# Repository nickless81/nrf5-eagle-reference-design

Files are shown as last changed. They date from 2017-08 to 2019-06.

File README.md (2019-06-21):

# Nordic semiconductor eagle reference design

## Reference designs


The reference designs supplied for eagle are made by following the [general pcb design guidelines][designguidenrf52] and referencing the [altium reference layout][altiumreference].
The eagle reference design is not the official reference designs, only the Altium reference designs has been tested and verified. They are available for download in Nordic's product pages.
The reference designs include eagle files as well as pdf printouts. For BOM see the altium reference designs.

* nRF51x22_qfaa
* nRF51x22_qfaa_dcdc
* nRF52832_qfaa
* nRF52832_qfaa_dcdc
* nRF52832_qfaa_nfc

## Libraries
**The libraries are not verified, only the Altium reference designs has been tested and verified.**

### Nordic_nRF
This library contains the nRF51 and nRF52 in qfn and bga packages, as well as; capacitors, inductors, and a 32MHz and 32kHz xtal. All that is needed for the core reference design. (link?)

### Nordic_misc
This library contains the rest of the components used in the sample eagle design(s) in this repository, as well as some simple antenna suggestions.

## Antenna
In the Nordic_misc library there is supplied some suggestions for antennas, please note that antenna characteristics depends greatly on the board layout. These antennas are made according to the [whitepaper][monopole] on quarter wave monopole 2.45 GHz antennas. Remember to [tune][antuning] the antenna

## NFC
An NFC listener antenna suggestion is supplied in the Nordic_misc library, this is the antenna used in the [nRF52-DK] development kit. Remember to [tune][nfctune] the antenna.

[github]: <https://github.com/NordicPlayground/nrf5-eagle-reference-design>
[designguidenrf51]: <https://devzone.nordicsemi.com/blogs/655/general-pcb-design-guidelines-for-nrf51/>
[designguidenrf52]: <https://devzone.nordicsemi.com/blogs/870/general-pcb-design-guidelines-for-nrf52/>
[referencecircuitry]: <https://infocenter.nordicsemi.com/index.jsp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>
[altiumreference]: <http://infocenter.nordicsemi.com/index.jsp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>
[nfctune]: <https://devzone.nordicsemi.com/blogs/957/nfc-tag-antenna-tuning/>
[nRF52-DK]: <http://www.nordicsemi.com/eng/Products/Bluetooth-low-energy2/nRF52-DK>
[dcdc_reference]: <nRF52832_qfaa_dcdc_reference.png>
[monopole]: <http://infocenter.nordicsemi.com/topic/com.nordic.infocenter.whitepapers/dita/whitepapers/pdflinks/nwp_008.html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>
[antuning]: <https://infocenter.nordicsemi.com/topic/com.nordic.infocenter.whitepapers/dita/whitepapers/pdflinks/nwp_017.html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>

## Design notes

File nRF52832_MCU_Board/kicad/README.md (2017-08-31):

## Reference designs
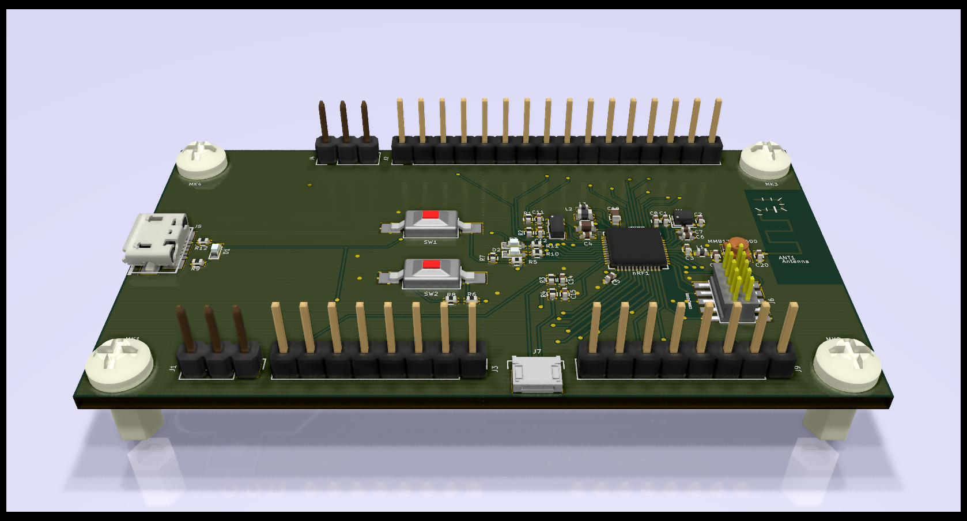
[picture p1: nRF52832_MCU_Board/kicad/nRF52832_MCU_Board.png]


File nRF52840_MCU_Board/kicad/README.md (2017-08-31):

## Reference designs
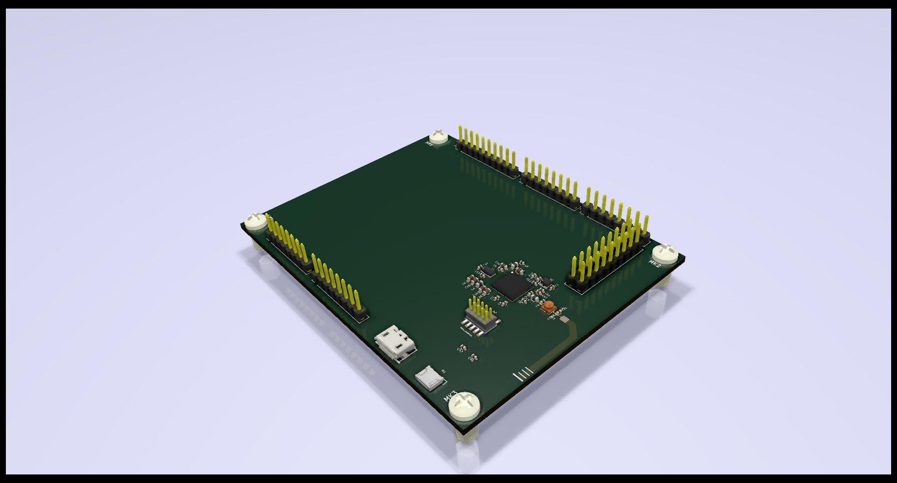
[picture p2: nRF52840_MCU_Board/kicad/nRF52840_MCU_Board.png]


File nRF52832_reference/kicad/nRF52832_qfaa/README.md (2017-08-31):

## Reference designs
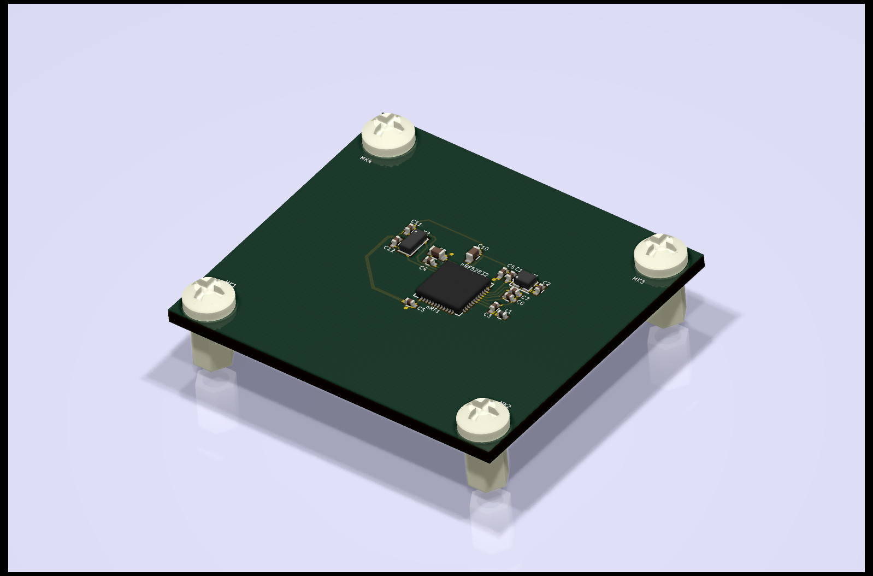
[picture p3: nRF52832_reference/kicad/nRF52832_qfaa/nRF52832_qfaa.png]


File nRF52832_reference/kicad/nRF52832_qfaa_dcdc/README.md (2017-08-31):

## Reference designs
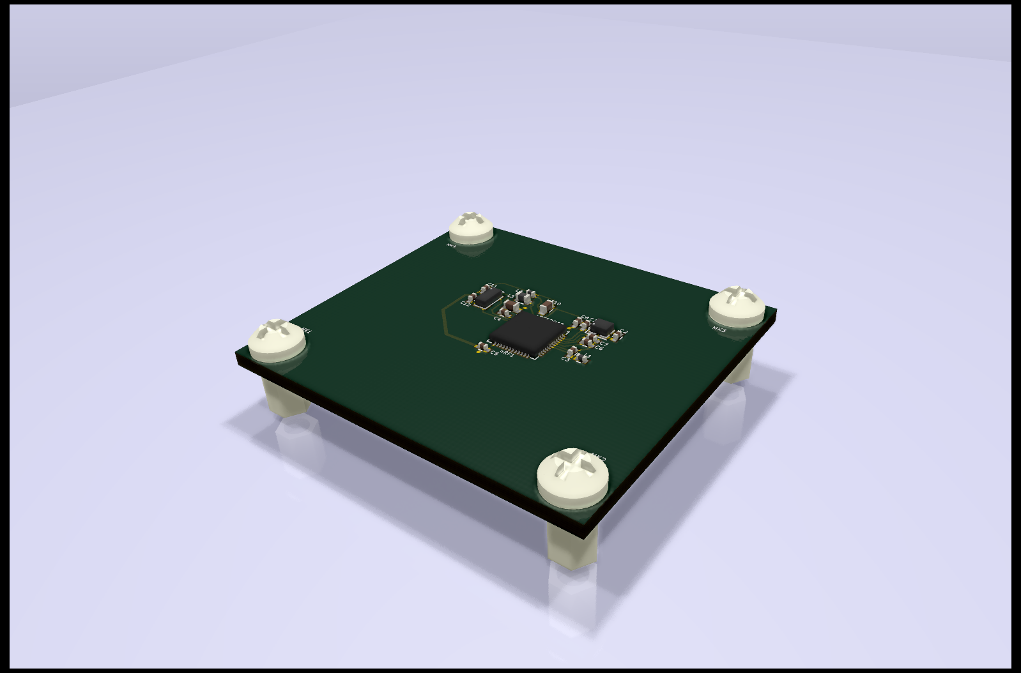
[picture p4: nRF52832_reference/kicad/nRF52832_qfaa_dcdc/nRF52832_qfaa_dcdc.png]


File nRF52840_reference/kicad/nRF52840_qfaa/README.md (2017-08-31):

## Reference designs
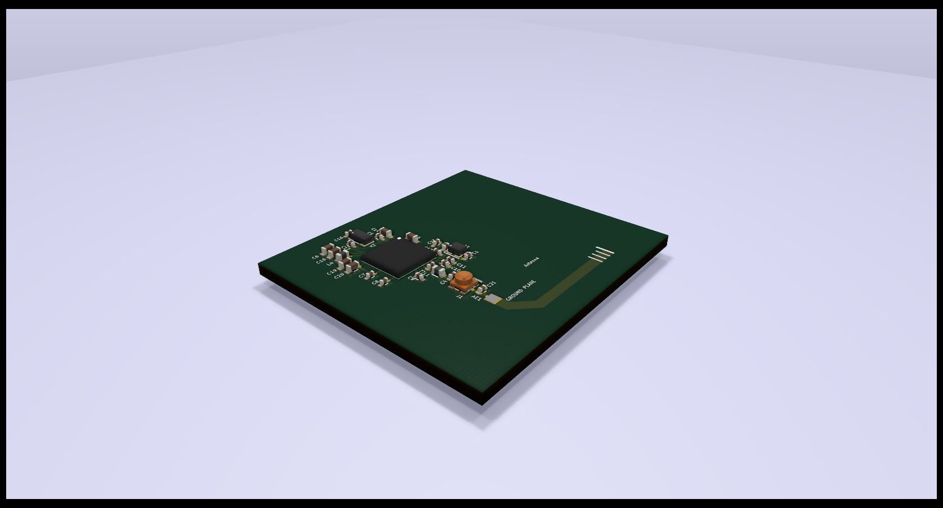
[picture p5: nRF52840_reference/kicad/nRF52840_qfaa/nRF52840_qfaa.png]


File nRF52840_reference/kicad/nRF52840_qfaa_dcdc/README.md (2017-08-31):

## Reference designs
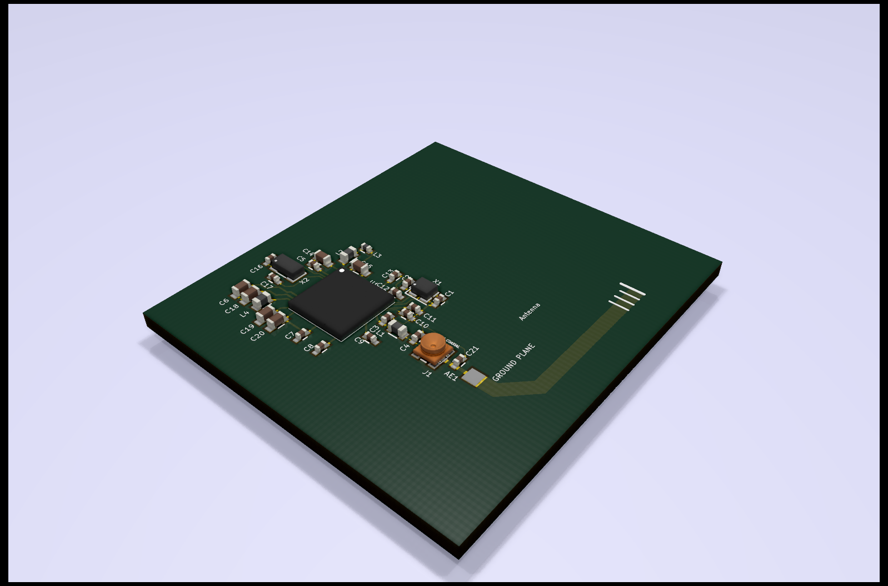
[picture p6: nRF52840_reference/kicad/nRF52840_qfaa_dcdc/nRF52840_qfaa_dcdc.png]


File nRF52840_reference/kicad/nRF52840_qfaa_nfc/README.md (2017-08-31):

## Reference designs
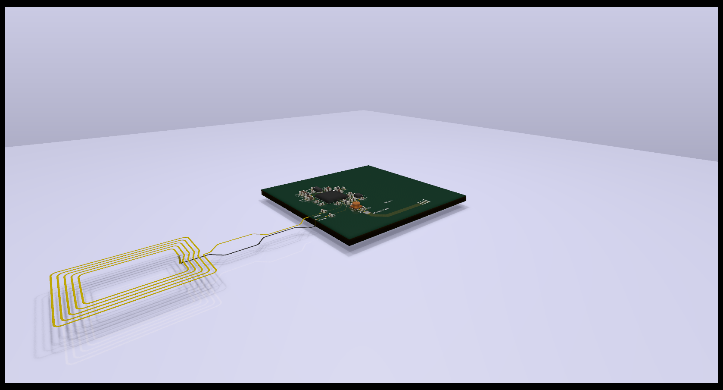
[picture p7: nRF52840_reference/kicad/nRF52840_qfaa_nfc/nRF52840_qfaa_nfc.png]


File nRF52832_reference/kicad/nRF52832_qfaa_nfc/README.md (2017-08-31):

## Reference designs
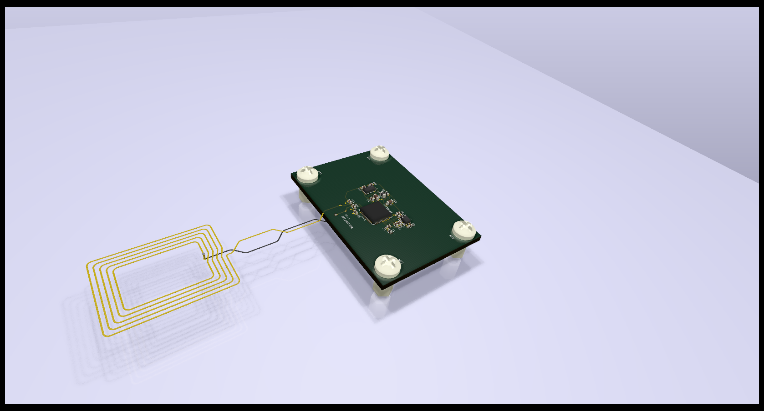
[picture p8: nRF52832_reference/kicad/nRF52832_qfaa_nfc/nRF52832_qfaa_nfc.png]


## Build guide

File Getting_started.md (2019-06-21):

# Getting started with nRF5 and CadSoft EAGLE (R)

Nordic Semiconductor already provides [reference designs][altiumreference] for Altium Designer (R), but if you prefer EAGLE here is a quick guide on how to use the EAGLE reference design.

This quick guide assumes you are familiar with doing PCB designs in EAGLE, otherwise both [Adafruit] and [SparkFun] have guides on how to get started.

1. First clone or download the reference designs and libraries from [Github]
2. Select the reference-design that fits your application (if you are uncertain use *nRF52832_qfaa_dcdc*)
3. Add your own parts in the circuit diagram
4. Create the layout and routing
	* Do not modify the geometry of the rf part

Please refer to the general pcb design guidelines for [nRF51][designguidenrf51] or [nRF52][designguidenrf52].

### 1. First clone or download the reference designs and libraries from [Github]

If you are familiar with [git] this is self explanatory, if not press the (green) "Clone or download" button and then "Download ZIP".

### 2. Select the reference-design that fits your application

All reference designs supplied here are for the QFN package.
If you want to use the internal ldo (not recommended) select nRF5\*_qfaa, if you want an example of nfc antenna usage select nRF5\*_qfaa_nfc.
You probably want the nRF51x2_qfaa_dcdc or nRF52832_qfaa_dcdc, for nRF51 or nRF52 respectively.

### 3. Add your own parts in the circuit diagram

Here is the part where you do your design, use your own libraries, use libraries supplied with eagle, use parts from the Nordic_misc library, make your own parts, etc.

### 4. Do the layout and routing

This is also a part of your regular workflow. Lay out your design next to or around the reference layout.

#### Do not modify the geometry of the rf part

Now, the important part: Do not add components close to the rf layout. This means around where you attach the antenna (the signal named RF).
The cutout in the ground plane is there for a reason. Add cutouts to any internal layers of the pcb as well. There should be a ground plane on the bottom layer.
Add a generous amount of ground stiching vias (remember vias are free).

### 5. Done

There. You are done with your nRF5 design in eagle, dont forget to run design reviews before ordering pcbs. And dont forget to tune the antenna when you have your prototype in hand.

# Some info on the git repository

## Reference designs


The reference designs supplied for eagle are made by following the [general pcb design guidelines][designguidenrf52] and referencing the [altium reference layout][altiumreference].
The reference designs include eagle files as well as pdf printouts. For BOM see the altium reference designs.

* nRF51x22_qfaa
* nRF51x22_qfaa_dcdc
* nRF52832_qfaa
* nRF52832_qfaa_dcdc
* nRF52832_qfaa_nfc

## Libraries

### Nordic_nRF
This library contains the nRF51 and nRF52 in QFN and bga packages, as well as; capacitors, inductors, and a 32MHz and 32kHz xtal. All that is needed for the core reference design.

### Nordic_misc
This library contains the rest of the components used in the sample eagle design(s) in the github repository, as well as some simple antenna suggestions.

## Antenna
In the Nordic_misc library there is supplied some suggestions for antennas, please note that antenna characteristics depends greatly on the board layout. These antennas are made according to the [whitepaper][monopole] on quarter wave monopole 2.45 GHz antennas. Remember to [tune][antuning] the antenna.

## NFC
An NFC listener antenna suggestion is supplied in the Nordic_misc library, this is the antenna used in the [nRF52-DK] development kit. Remember to [tune][nfctune] the antenna.

[sparkfun]: <https://www.sparkfun.com/>
[adafruit]: <https://www.adafruit.com/>
[github]: <https://github.com/NordicPlayground/nrf5-eagle-reference-design>
[designguidenrf51]: <https://devzone.nordicsemi.com/blogs/655/general-pcb-design-guidelines-for-nrf51/>
[designguidenrf52]: <https://devzone.nordicsemi.com/blogs/870/general-pcb-design-guidelines-for-nrf52/>
[referencecircuitry]: <https://infocenter.nordicsemi.com/index.jsp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>
[altiumreference]: <http://infocenter.nordicsemi.com/index.jsp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>
[nfctune]: <https://devzone.nordicsemi.com/blogs/957/nfc-tag-antenna-tuning/>
[nRF52-DK]: <http://www.nordicsemi.com/eng/Products/Bluetooth-low-energy2/nRF52-DK>
[dcdc_reference]: <nRF52832_qfaa_dcdc_reference.png>
[monopole]: <http://infocenter.nordicsemi.com/topic/com.nordic.infocenter.whitepapers/dita/whitepapers/pdflinks/nwp_008.html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>
[antuning]: <https://infocenter.nordicsemi.com/topic/com.nordic.infocenter.whitepapers/dita/whitepapers/pdflinks/nwp_017.html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>
[git]: <https://git-scm.com/>

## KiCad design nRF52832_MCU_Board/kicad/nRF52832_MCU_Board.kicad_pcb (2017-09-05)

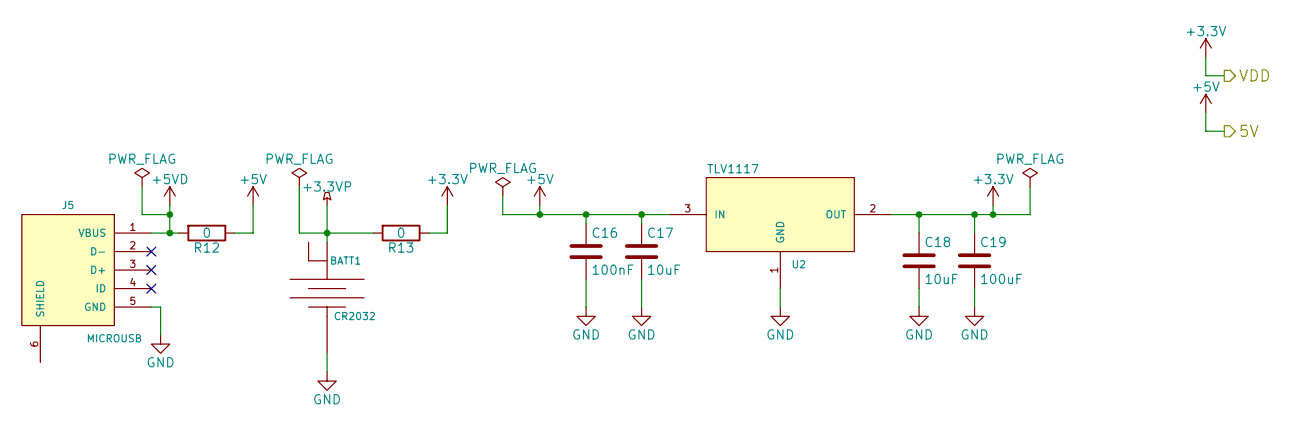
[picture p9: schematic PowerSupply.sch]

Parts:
BATT1: CR2032; keystone_3003
C16: 100nF; C_0402
C17, C18: 10uF; C_0603
C19: 100uF; C_0805
J5: MICROUSB; conn_usb_B_micro_smd
R12, R13: 0; R_0402
U2: TLV1117; SOT-223-3Lead_TabPin2

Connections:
+3.3VP: BATT1.2 (+), R13.2
+3V3: C18.1, C19.1, R13.1, U2.2 (OUT); also elsewhere on the board
+5V: C16.1, C17.1, R12.1, U2.3 (IN); also elsewhere on the board
+5VD: J5.1 (VBUS), R12.2
GND: BATT1.1 (-), C16.2, C17.2, C18.2, C19.2, J5.5 (GND), U2.1 (GND); also elsewhere on the board

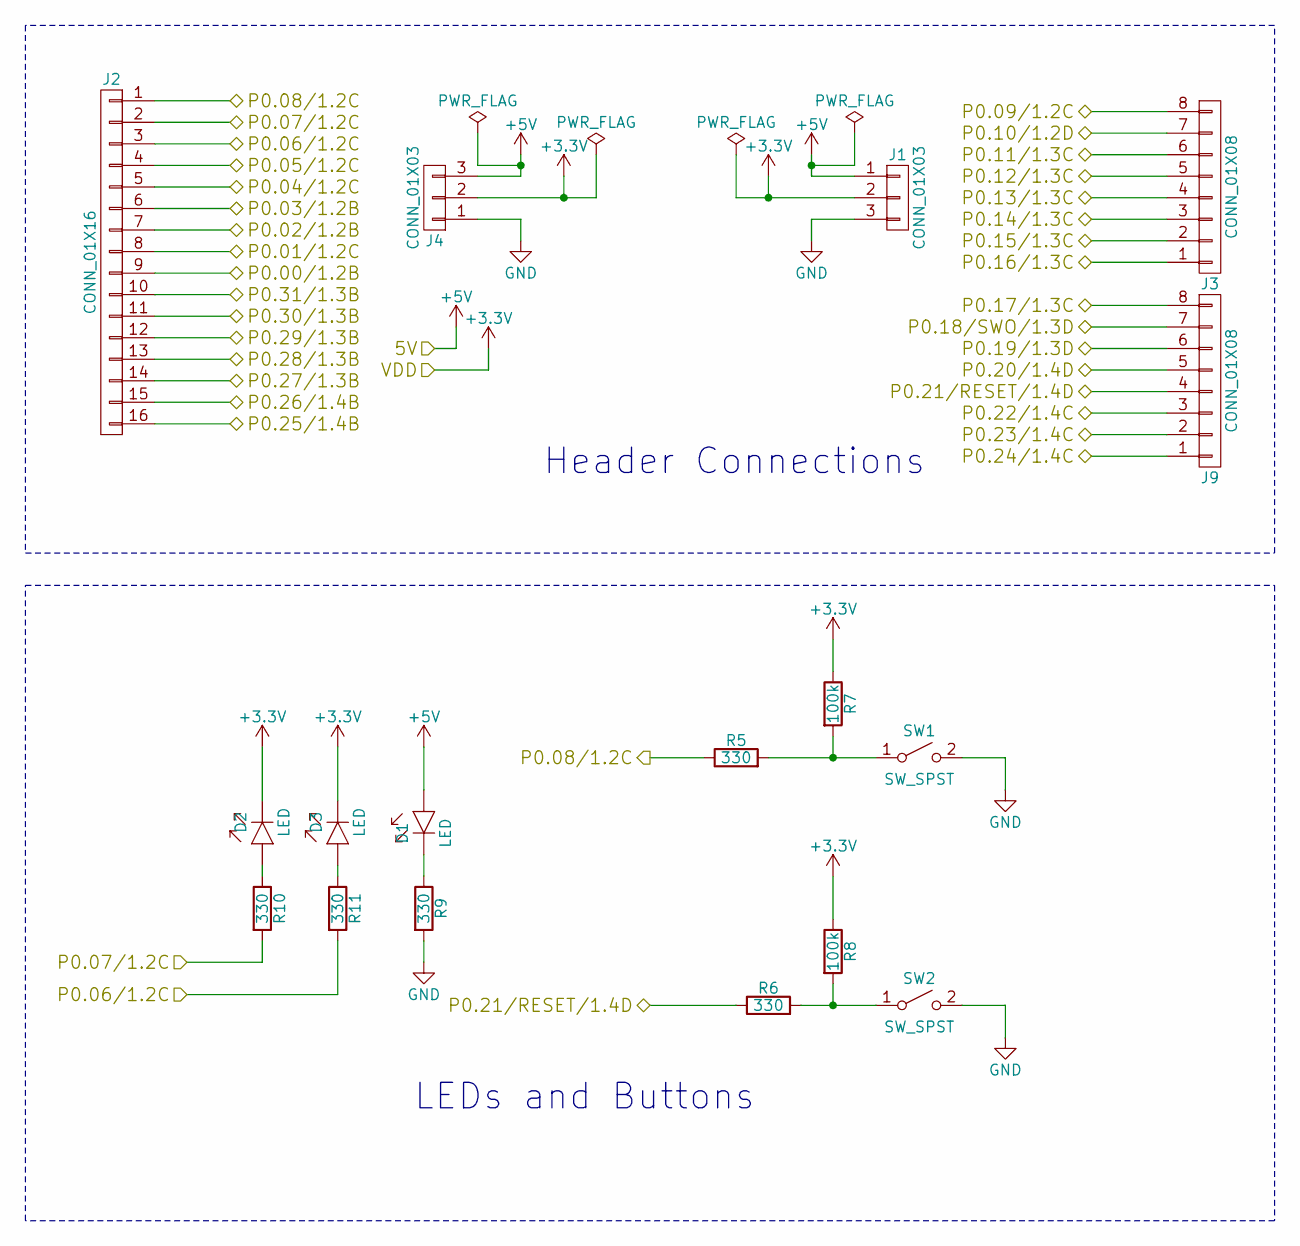
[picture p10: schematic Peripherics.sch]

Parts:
D1, D2, D3: LED; LED_0603
J1, J4: CONN_01X03; Pin_Header_Straight_1x03_Pitch2.54mm
J2: CONN_01X16; Pin_Header_Straight_1x16_Pitch2.54mm
J3, J9: CONN_01X08; Pin_Header_Straight_1x08_Pitch2.54mm
R5, R6, R9, R10, R11: 330; R_0402
R7, R8: 100k; R_0402
SW1, SW2: SW_SPST; SW_SPST_FSMSM

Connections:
+3V3: D2.1 (C), D3.1 (C), J1.2, J4.2, R7.1, R8.1; also elsewhere on the board
+5V: D1.2 (A), J1.1, J4.3; also elsewhere on the board
/P0.00: J2.9; also elsewhere on the board
/P0.01: J2.8; also elsewhere on the board
/P0.02: J2.7; also elsewhere on the board
/P0.03: J2.6; also elsewhere on the board
/P0.04: J2.5; also elsewhere on the board
/P0.05: J2.4; also elsewhere on the board
/P0.06: J2.3, R11.2; also elsewhere on the board
/P0.07: J2.2, R10.2; also elsewhere on the board
/P0.08: J2.1, R5.1; also elsewhere on the board
/P0.09: J3.8; also elsewhere on the board
/P0.10: J3.7; also elsewhere on the board
/P0.11: J3.6; also elsewhere on the board
/P0.12: J3.5; also elsewhere on the board
/P0.13: J3.4; also elsewhere on the board
/P0.14: J3.3; also elsewhere on the board
/P0.15: J3.2; also elsewhere on the board
/P0.16: J3.1; also elsewhere on the board
/P0.17: J9.8; also elsewhere on the board
/P0.18: J9.7; also elsewhere on the board
/P0.19: J9.6; also elsewhere on the board
/P0.20: J9.5; also elsewhere on the board
/P0.21: J9.4, R6.1; also elsewhere on the board
/P0.22: J9.3; also elsewhere on the board
/P0.23: J9.2; also elsewhere on the board
/P0.24: J9.1; also elsewhere on the board
/P0.25: J2.16; also elsewhere on the board
/P0.26: J2.15; also elsewhere on the board
/P0.27: J2.14; also elsewhere on the board
/P0.28: J2.13; also elsewhere on the board
/P0.29: J2.12; also elsewhere on the board
/P0.30: J2.11; also elsewhere on the board
/P0.31: J2.10; also elsewhere on the board
GND: J1.3, J4.1, R9.2, SW1.2 (B), SW2.2 (B); also elsewhere on the board
unnamed: D1.1 (C), R9.1
unnamed: D2.2 (A), R10.1
unnamed: D3.2 (A), R11.1
unnamed: R5.2, R7.2, SW1.1 (A)
unnamed: R6.2, R8.2, SW2.1 (A)

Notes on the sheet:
Header Connections
LEDs and Buttons

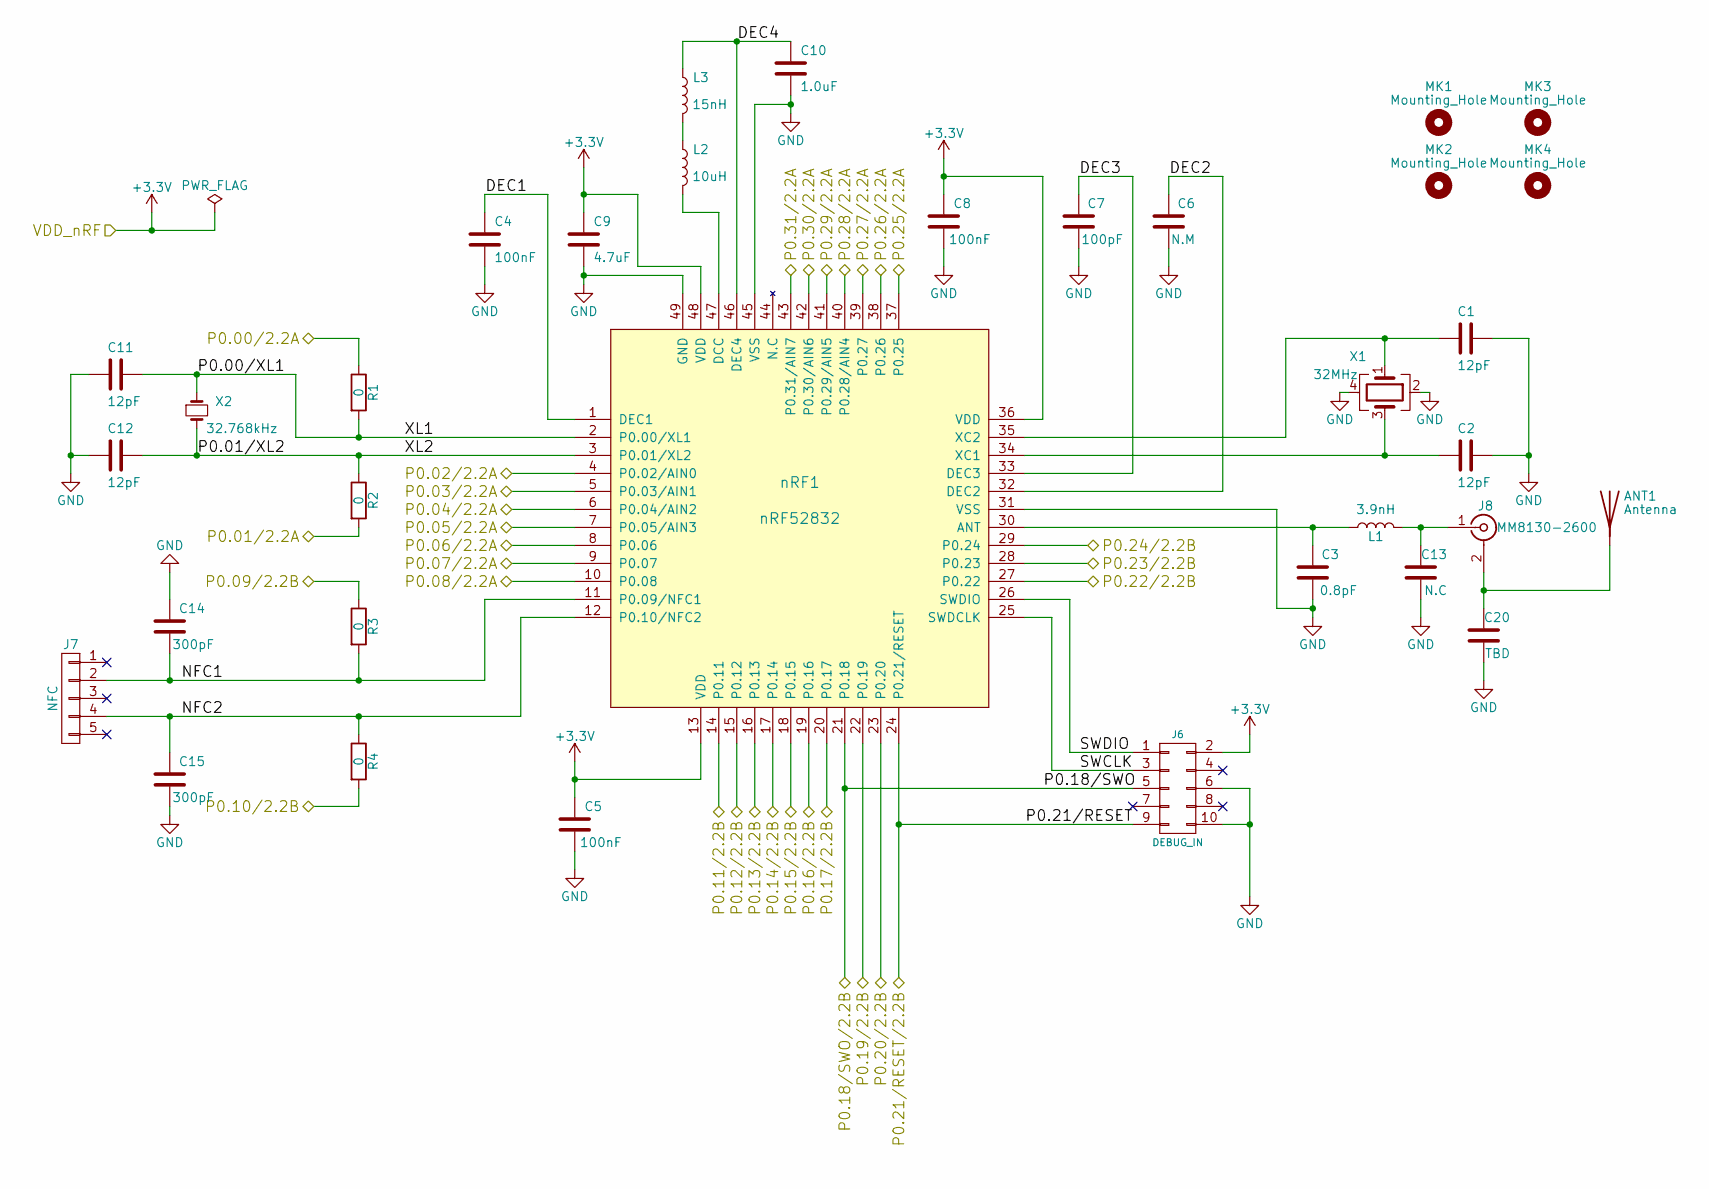
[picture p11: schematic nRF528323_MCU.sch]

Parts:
ANT1: Antenna; Nordic_misc-QWMP_MEANDERED_LEFT_+6
C1, C2, C11, C12: 12pF; C_0402
C3: 0.8pF; C_0402
C4, C5, C8: 100nF; C_0402
C6: N.M; C_0402
C7: 100pF; C_0402
C9: 4.7uF; C_0603
C10: 1.0uF; C_0603
C13: N.C; C_0402
C14, C15: 300pF; C_0402
C20: TBD; C_0402
J6: DEBUG_IN; ftsh-105-01-l-dv
J7: NFC; Nordic_misc-FPC_05P-RA-SMD
J8: MM8130-2600; Nordic_misc-MM8130-2600
L1: 3.9nH; L_0402
L2: 10uH; L_0603
L3: 15nH; L_0402
MK1, MK2, MK3, MK4: Mounting_Hole; MountingHole_3mm
R1, R2, R3, R4: 0; R_0402
X1: 32MHz; Crystal_SMD_2016-4pin_2.0x1.6mm
X2: 32.768kHz; Crystal_SMD_3215-2pin_3.2x1.5mm
nRF1: nRF52832; Nordic_nRF-QFN40P600X600X90-48_N

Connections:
+3V3: C5.1, C8.1, C9.1, J6.2, nRF1.13 (VDD), nRF1.36 (VDD), nRF1.48 (VDD); also elsewhere on the board
/P0.00: R1.1; also elsewhere on the board
/P0.01: R2.2; also elsewhere on the board
/P0.02: nRF1.4 (P0.02/AIN0); also elsewhere on the board
/P0.03: nRF1.5 (P0.03/AIN1); also elsewhere on the board
/P0.04: nRF1.6 (P0.04/AIN2); also elsewhere on the board
/P0.05: nRF1.7 (P0.05/AIN3); also elsewhere on the board
/P0.06: nRF1.8 (P0.06); also elsewhere on the board
/P0.07: nRF1.9 (P0.07); also elsewhere on the board
/P0.08: nRF1.10 (P0.08); also elsewhere on the board
/P0.09: R3.1; also elsewhere on the board
/P0.10: R4.2; also elsewhere on the board
/P0.11: nRF1.14 (P0.11); also elsewhere on the board
/P0.12: nRF1.15 (P0.12); also elsewhere on the board
/P0.13: nRF1.16 (P0.13); also elsewhere on the board
/P0.14: nRF1.17 (P0.14); also elsewhere on the board
/P0.15: nRF1.18 (P0.15); also elsewhere on the board
/P0.16: nRF1.19 (P0.16); also elsewhere on the board
/P0.17: nRF1.20 (P0.17); also elsewhere on the board
/P0.18: J6.5, nRF1.21 (P0.18); also elsewhere on the board
/P0.19: nRF1.22 (P0.19); also elsewhere on the board
/P0.20: nRF1.23 (P0.20); also elsewhere on the board
/P0.21: J6.9, nRF1.24 (P0.21/RESET); also elsewhere on the board
/P0.22: nRF1.27 (P0.22); also elsewhere on the board
/P0.23: nRF1.28 (P0.23); also elsewhere on the board
/P0.24: nRF1.29 (P0.24); also elsewhere on the board
/P0.25: nRF1.37 (P0.25); also elsewhere on the board
/P0.26: nRF1.38 (P0.26); also elsewhere on the board
/P0.27: nRF1.39 (P0.27); also elsewhere on the board
/P0.28: nRF1.40 (P0.28/AIN4); also elsewhere on the board
/P0.29: nRF1.41 (P0.29/AIN5); also elsewhere on the board
/P0.30: nRF1.42 (P0.30/AIN6); also elsewhere on the board
/P0.31: nRF1.43 (P0.31/AIN7); also elsewhere on the board
/nRF528323_MCU/DEC1: C4.1, nRF1.1 (DEC1)
/nRF528323_MCU/DEC2: C6.2, nRF1.32 (DEC2)
/nRF528323_MCU/DEC3: C7.2, nRF1.33 (DEC3)
/nRF528323_MCU/DEC4: C10.1, L3.1, nRF1.46 (DEC4)
/nRF528323_MCU/NFC1: C14.2, J7.2, R3.2, nRF1.11 (P0.09/NFC1)
/nRF528323_MCU/NFC2: C15.1, J7.4, R4.1, nRF1.12 (P0.10/NFC2)
/nRF528323_MCU/P0.00/XL1: C11.1, R1.2, X2.1, nRF1.2 (P0.00/XL1)
/nRF528323_MCU/P0.01/XL2: C12.1, R2.1, X2.2, nRF1.3 (P0.01/XL2)
/nRF528323_MCU/SWCLK: J6.3, nRF1.25 (SWDCLK)
/nRF528323_MCU/SWDIO: J6.1, nRF1.26 (SWDIO)
GND: C1.1, C2.1, C3.1, C4.2, C5.2, C6.1, C7.1, C8.2, C9.2, C10.2, C11.2, C12.2, C13.1, C14.1, C15.2, C20.1, J6.6, J6.10, X1.2, X1.4, nRF1.31 (VSS), nRF1.45 (VSS), nRF1.49 (GND); also elsewhere on the board
unnamed: ANT1.1, C20.2, J8.2 (Ext)
unnamed: C1.2, X1.1, nRF1.35 (XC2)
unnamed: C2.2, X1.3, nRF1.34 (XC1)
unnamed: C3.2, L1.1, nRF1.30 (ANT)
unnamed: C13.2, J8.1 (In), L1.2
unnamed: L2.1, L3.2
unnamed: L2.2, nRF1.47 (DCC)

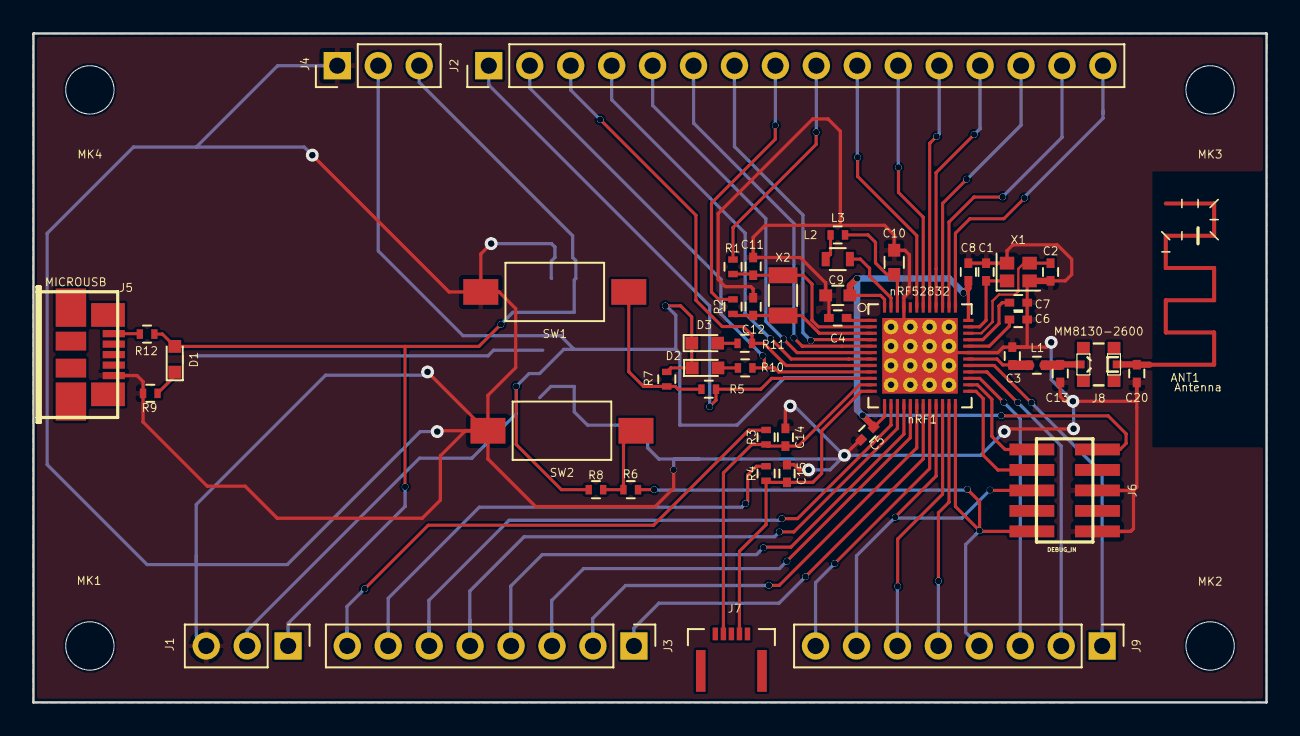
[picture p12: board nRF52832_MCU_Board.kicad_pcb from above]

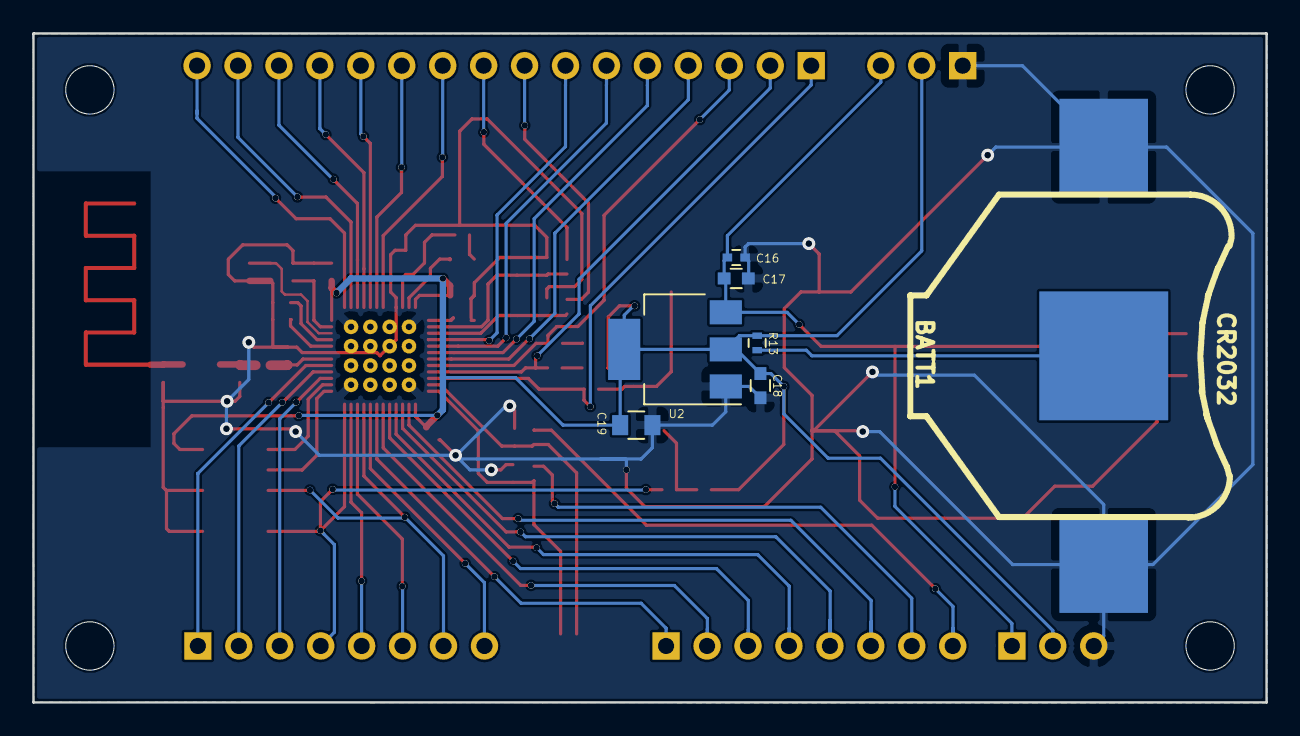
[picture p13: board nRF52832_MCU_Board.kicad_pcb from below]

Board: 2 copper layers, 76.5 x 41.5 mm, 60 parts (7 on the bottom side), 59 nets.

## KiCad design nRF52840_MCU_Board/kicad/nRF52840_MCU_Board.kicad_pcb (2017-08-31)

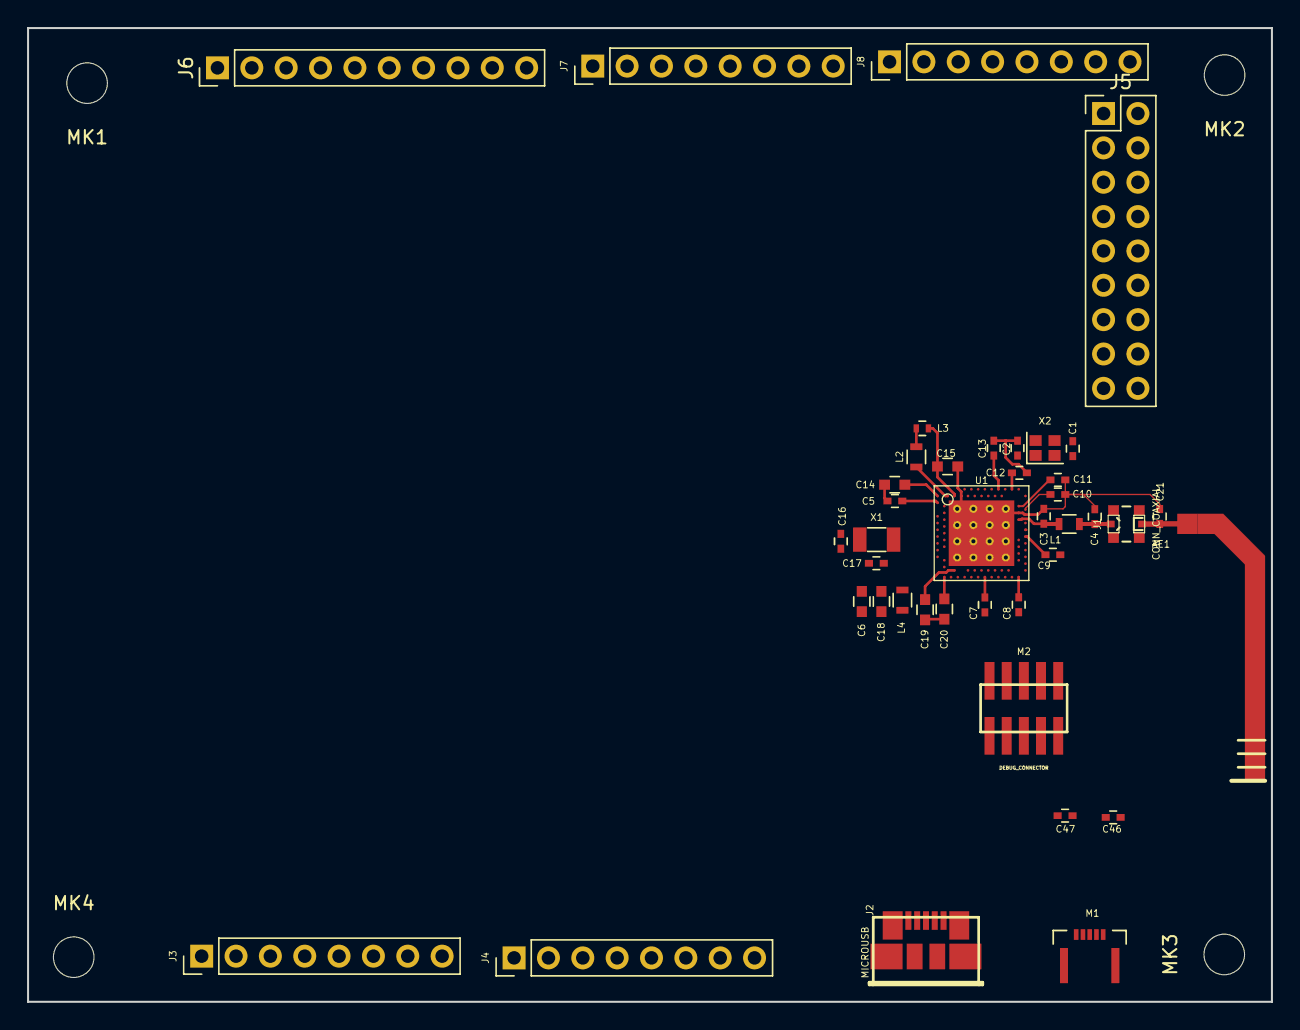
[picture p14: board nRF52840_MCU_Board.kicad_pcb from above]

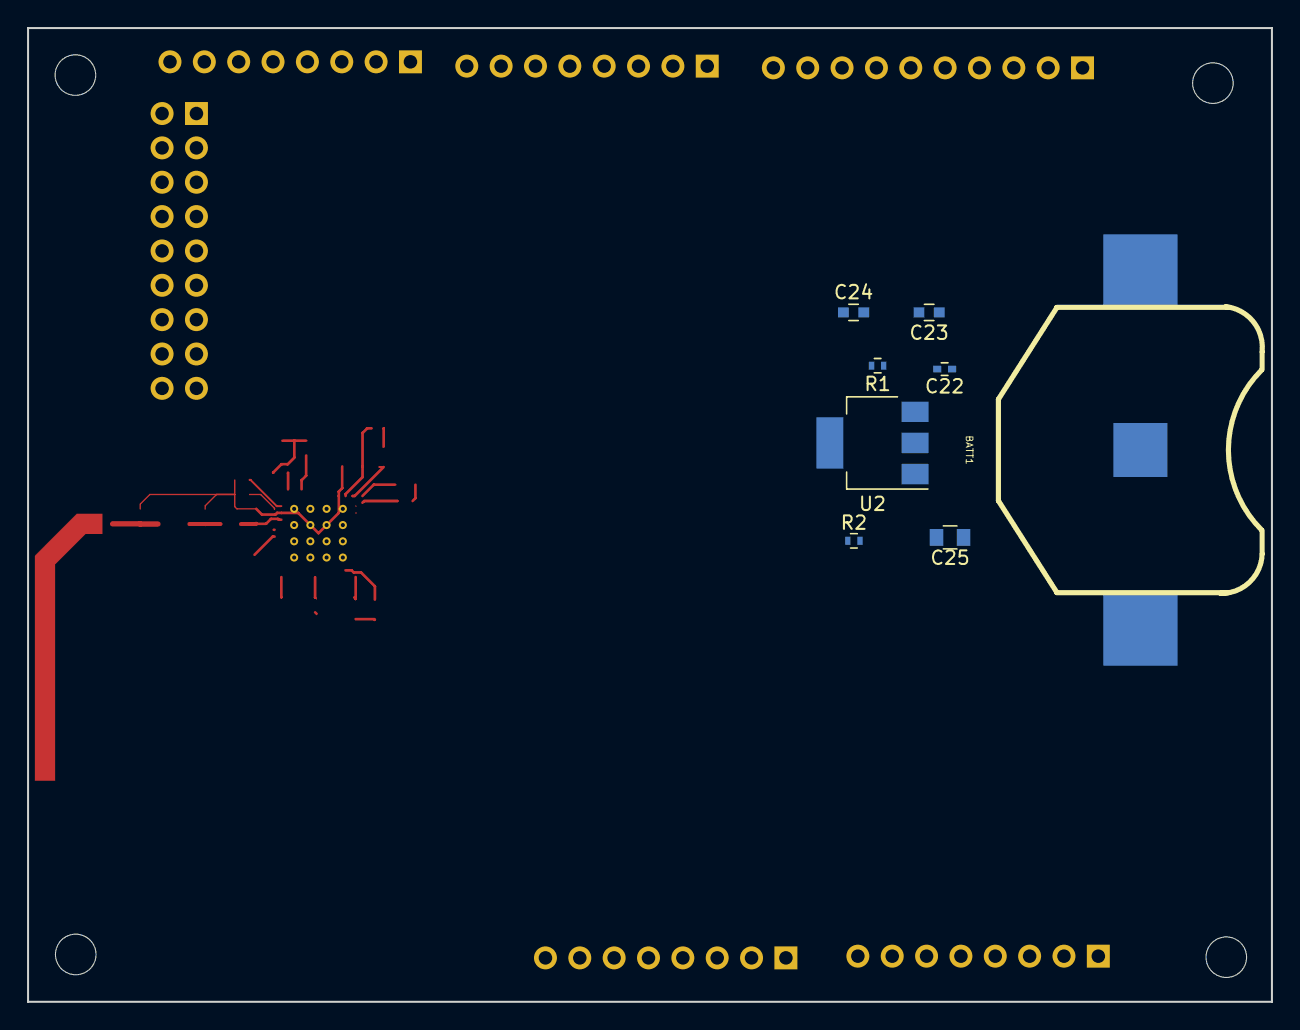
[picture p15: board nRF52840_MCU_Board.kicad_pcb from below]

Board: 2 copper layers, 92.0 x 72.0 mm, 53 parts (8 on the bottom side), 33 nets.

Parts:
AE1: Antenna; Nordic_misc-QWMP_BEND_RIGHT_+0
BATT1: CR2032; keystone_3002
C1, C2, C16, C17: 12pF; C_0402
C3: 0.8pF; C_0402
C4: 0.5pF; C_0402
C5, C7, C8, C12, C22: 100nF; C_0402
C6, C18, C19, C20: 4.7uF; C_0603
C9, C10, C13: N.C; C_0402
C11: 100pF; C_0402
C14, C15: 1.0uF; C_0603
C21: 1.2pF; C_0402
C23, C24: 10uF; C_0603
C25: 100uF; C_0805
C46, C47: 300pF; C_0402
J1: CONN_COAXIAL; Nordic_misc-MM8130-2600
J2: MICROUSB; conn_usb_B_micro_smd
J3: Power; Pin_Header_Straight_1x08_Pitch2.54mm
J4: Analog; Pin_Header_Straight_1x08_Pitch2.54mm
J5: Digital3; Pin_Header_Straight_2x09_Pitch2.54mm
J6: Digital0; Pin_Header_Straight_1x10_Pitch2.54mm
J7: Digital1; Pin_Header_Straight_1x08_Pitch2.54mm
J8: Digital2; Pin_Header_Straight_1x08_Pitch2.54mm
L1: 3.3nH; L_0603
L2, L4: 10uH; L_0603
L3: 15nH; L_0402
M1: FPC_05P-RA-SMD; Nordic_misc-FPC_05P-RA-SMD
M2: DEBUG_CONNECTOR; ftsh-105-01-l-dv
MK1, MK2, MK3, MK4: Mounting_Hole; MountingHole_3mm
R1, R2: 0; R_0402
U1: nRF52840; AQFN73_7x7mm
U2: TLV1117; SOT-223-3Lead_TabPin2
X1: XTAL_32KHZ; Crystal_SMD_3215-2pin_3.2x1.5mm
X2: XTAL_32MHZ; Crystal_SMD_2016-4pin_2.0x1.6mm

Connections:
+3.3VP: BATT1.2, R2.2
+3V3: C6.1, C7.1, C8.1, C12.1, C14.1, C20.1, C24.1, C25.1, L4.1, M2.1, R2.1, U1.A22, U1.AD2, U1.AD14, U1.AD23, U1.B1, U1.W1, U2.2
+5V: C22.1, C23.1, R1.1, U2.3
+5VD: J2.1, R1.2
/D+: J2.3, U1.AD6
/D-: J2.2, U1.AD4
/nRF52840/NFC1: C47.2, M1.2, U1.L24
/nRF52840/NFC2: C46.1, M1.4, U1.J24
/nRF52840/P0.18/RESET: M2.10, U1.AC13
/nRF52840/P1.00: M2.6, U1.AD22
GND: BATT1.1, C1.1, C2.1, C3.1, C4.1, C5.2, C6.2, C7.2, C8.2, C9.2, C10.1, C11.1, C12.2, C13.2, C14.2, C15.2, C18.2, C19.2, C20.2, C21.1, C22.2, C23.2, C24.2, C25.2, C46.2, C47.1, J2.5, M2.3, M2.5, M2.9, U1.74, U1.B7, U1.F23, U2.1, X2.2, X2.4
unnamed: C21.2, J1.2
unnamed: C1.2, U1.B24, X2.3
unnamed: C2.2, U1.A23, X2.1
unnamed: C3.2, L1.1, U1.H23
unnamed: C4.2, J1.1, L1.2
unnamed: C5.1, U1.C1
unnamed: C9.1, U1.N24
unnamed: C10.2, U1.E24
unnamed: C11.2, U1.D23
unnamed: C13.1, U1.A18
unnamed: C15.1, L3.1, U1.B5
unnamed: C16.1, U1.D2
unnamed: C16.2, X1.1
unnamed: C17.1, U1.F2
unnamed: C17.2, X1.2
unnamed: C19.1, U1.AC5
unnamed: L2.1, L3.2
unnamed: L2.2, U1.B3
unnamed: L4.2, U1.AB2
unnamed: M2.2, U1.AC24
unnamed: M2.4, U1.AA24
VDD: C18.1, U1.Y2

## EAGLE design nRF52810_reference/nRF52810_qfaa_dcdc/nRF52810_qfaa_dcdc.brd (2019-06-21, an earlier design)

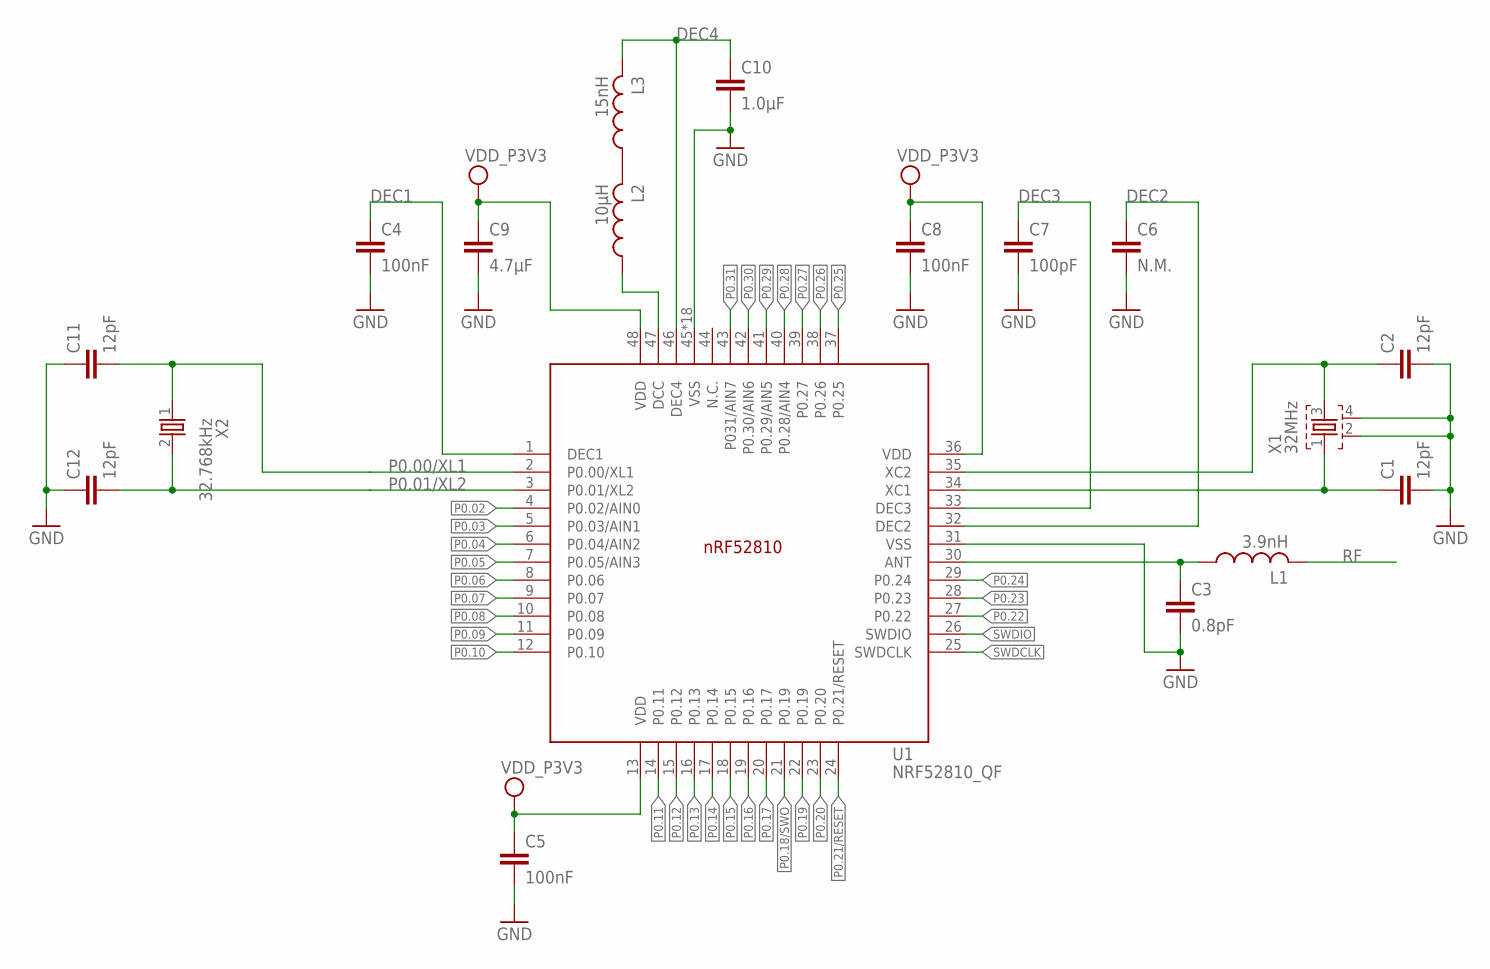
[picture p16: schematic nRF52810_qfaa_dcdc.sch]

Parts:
C1, C2, C11, C12: 12pF; RESC0402_N
C3: 0.8pF; RESC0402_N
C4, C5, C8: 100nF; RESC0402_N
C6: N.M.; RESC0402_N
C7: 100pF; RESC0402_N
C9: 4.7µF; RESC0603_N
C10: 1.0µF; RESC0603_N
L1: 3.9nH; RESC0402_N
L2: 10µH; RESC0603_N
L3: 15nH; RESC0402_N
U1: NRF52810_QF; QFN40P600X600X90-48_N
X1: 32MHz; BT-XTAL_2016_N
X2: 32.768kHz; XTAL_3215_N

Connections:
ANT: C3.1, L1.1, U1.30 (ANT)
DEC1: C4.1, U1.1 (DEC1)
DEC2: C6.1, U1.32 (DEC2)
DEC3: C7.1, U1.33 (DEC3)
DEC4: C10.1, L3.2, U1.46 (DEC4)
GND: C1.2, C2.2, C3.2, C4.2, C5.2, C6.2, C7.2, C8.2, C9.2, C10.2, C11.1, C12.1, U1.31 (VSS), U1.45 (VSS), U1.PAD (VSS), U1.PAD@VIA01 (VSS), U1.PAD@VIA02 (VSS), U1.PAD@VIA03 (VSS), U1.PAD@VIA04 (VSS), U1.PAD@VIA05 (VSS), U1.PAD@VIA06 (VSS), U1.PAD@VIA07 (VSS), U1.PAD@VIA08 (VSS), U1.PAD@VIA09 (VSS), U1.PAD@VIA10 (VSS), U1.PAD@VIA11 (VSS), U1.PAD@VIA12 (VSS), U1.PAD@VIA13 (VSS), U1.PAD@VIA14 (VSS), U1.PAD@VIA15 (VSS), U1.PAD@VIA16 (VSS), X1.2, X1.4
unnamed: L2.2, L3.1
unnamed: C2.1, U1.35 (XC2), X1.3
unnamed: L2.1, U1.47 (DCC)
P0.00/XL1: C11.2, U1.2 (P0.00/XL1), X2.1
P0.01/XL2: C12.2, U1.3 (P0.01/XL2), X2.2
P0.02: U1.4 (P0.02/AIN0)
P0.03: U1.5 (P0.03/AIN1)
P0.04: U1.6 (P0.04/AIN2)
P0.05: U1.7 (P0.05/AIN3)
P0.06: U1.8 (P0.06)
P0.07: U1.9 (P0.07)
P0.08: U1.10 (P0.08)
P0.09: U1.11 (P0.09)
P0.10: U1.12 (P0.10)
P0.11: U1.14 (P0.11)
P0.12: U1.15 (P0.12)
P0.13: U1.16 (P0.13)
P0.14: U1.17 (P0.14)
P0.15: U1.18 (P0.15)
P0.16: U1.19 (P0.16)
P0.17: U1.20 (P0.17)
P0.18/SWO: U1.21 (P0.19)
P0.19: U1.22 (P0.19)
P0.20: U1.23 (P0.20)
P0.21/RESET: U1.24 (P0.21/RESET)
P0.22: U1.27 (P0.22)
P0.23: U1.28 (P0.23)
P0.24: U1.29 (P0.24)
P0.25: U1.37 (P0.25)
P0.26: U1.38 (P0.26)
P0.27: U1.39 (P0.27)
P0.28: U1.40 (P0.28/AIN4)
P0.29: U1.41 (P0.29/AIN5)
P0.30: U1.42 (P0.30/AIN6)
P0.31: U1.43 (P031/AIN7)
RF: L1.2
SWDCLK: U1.25 (SWDCLK)
SWDIO: U1.26 (SWDIO)
VDD_P3V3: C5.1, C8.1, C9.1, U1.13 (VDD), U1.36 (VDD), U1.48 (VDD)
X1: C1.1, U1.34 (XC1), X1.1

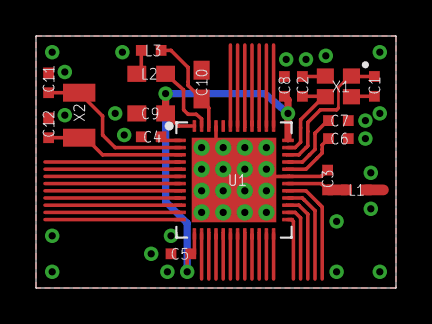
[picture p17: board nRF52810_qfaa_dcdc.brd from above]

Board: 2 copper layers, 20.0 x 14.0 mm, 18 parts (0 on the bottom side), 13 nets.

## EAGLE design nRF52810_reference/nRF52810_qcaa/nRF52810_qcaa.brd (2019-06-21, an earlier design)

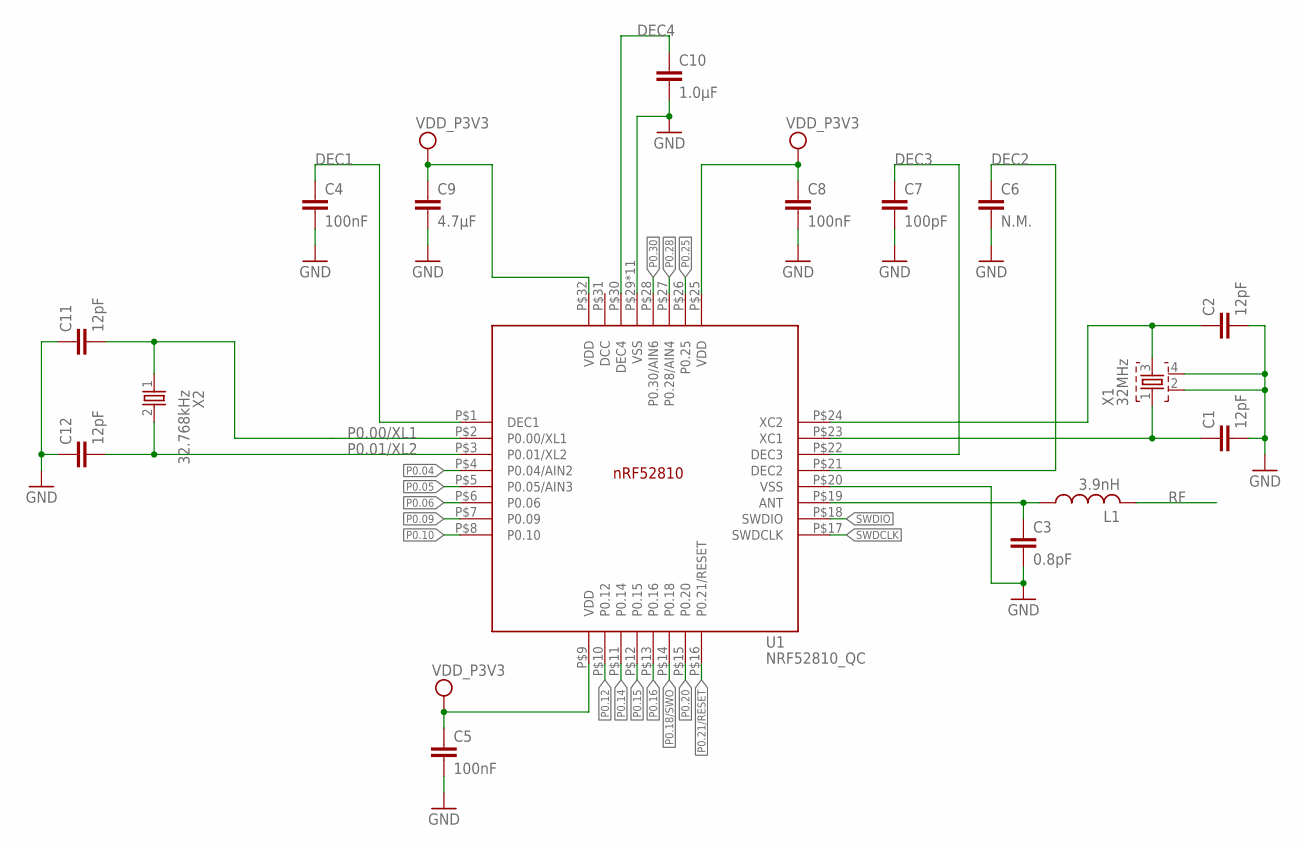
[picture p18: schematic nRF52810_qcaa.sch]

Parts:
C1, C2, C11, C12: 12pF; RESC0402_N
C3: 0.8pF; RESC0402_N
C4, C5, C8: 100nF; RESC0402_N
C6: N.M.; RESC0402_N
C7: 100pF; RESC0402_N
C9: 4.7µF; RESC0603_N
C10: 1.0µF; RESC0603_N
L1: 3.9nH; RESC0402_N
U1: NRF52810_QC; QFN50P500X500X90-32_N
X1: 32MHz; BT-XTAL_2016_N
X2: 32.768kHz; XTAL_3215_N

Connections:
ANT: C3.1, L1.1, U1.P$19 (ANT)
DEC1: C4.1, U1.P$1 (DEC1)
DEC2: C6.1, U1.P$21 (DEC2)
DEC3: C7.1, U1.P$22 (DEC3)
DEC4: C10.1, U1.P$30 (DEC4)
GND: C1.2, C2.2, C3.2, C4.2, C5.2, C6.2, C7.2, C8.2, C9.2, C10.2, C11.1, C12.1, U1.P$20 (VSS), U1.P$29 (VSS), U1.P$33 (VSS), U1.P$34 (VSS), U1.P$35 (VSS), U1.P$36 (VSS), U1.P$37 (VSS), U1.P$38 (VSS), U1.P$39 (VSS), U1.P$40 (VSS), U1.P$41 (VSS), U1.P$42 (VSS), X1.2, X1.4
unnamed: C2.1, U1.P$24 (XC2), X1.3
P0.00/XL1: C11.2, U1.P$2 (P0.00/XL1), X2.1
P0.01/XL2: C12.2, U1.P$3 (P0.01/XL2), X2.2
P0.04: U1.P$4 (P0.04/AIN2)
P0.05: U1.P$5 (P0.05/AIN3)
P0.06: U1.P$6 (P0.06)
P0.09: U1.P$7 (P0.09)
P0.10: U1.P$8 (P0.10)
P0.12: U1.P$10 (P0.12)
P0.14: U1.P$11 (P0.14)
P0.15: U1.P$12 (P0.15)
P0.16: U1.P$13 (P0.16)
P0.18/SWO: U1.P$14 (P0.18)
P0.20: U1.P$15 (P0.20)
P0.21/RESET: U1.P$16 (P0.21/RESET)
P0.25: U1.P$26 (P0.25)
P0.28: U1.P$27 (P0.28/AIN4)
P0.30: U1.P$28 (P0.30/AIN6)
RF: L1.2
SWDCLK: U1.P$17 (SWDCLK)
SWDIO: U1.P$18 (SWDIO)
VDD_P3V3: C5.1, C8.1, C9.1, U1.P$9 (VDD), U1.P$25 (VDD), U1.P$32 (VDD)
X1: C1.1, U1.P$23 (XC1), X1.1

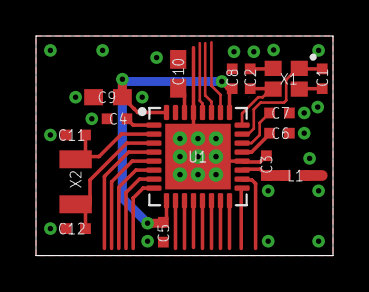
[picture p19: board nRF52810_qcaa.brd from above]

Board: 2 copper layers, 16.5 x 12.2 mm, 16 parts (0 on the bottom side), 11 nets.

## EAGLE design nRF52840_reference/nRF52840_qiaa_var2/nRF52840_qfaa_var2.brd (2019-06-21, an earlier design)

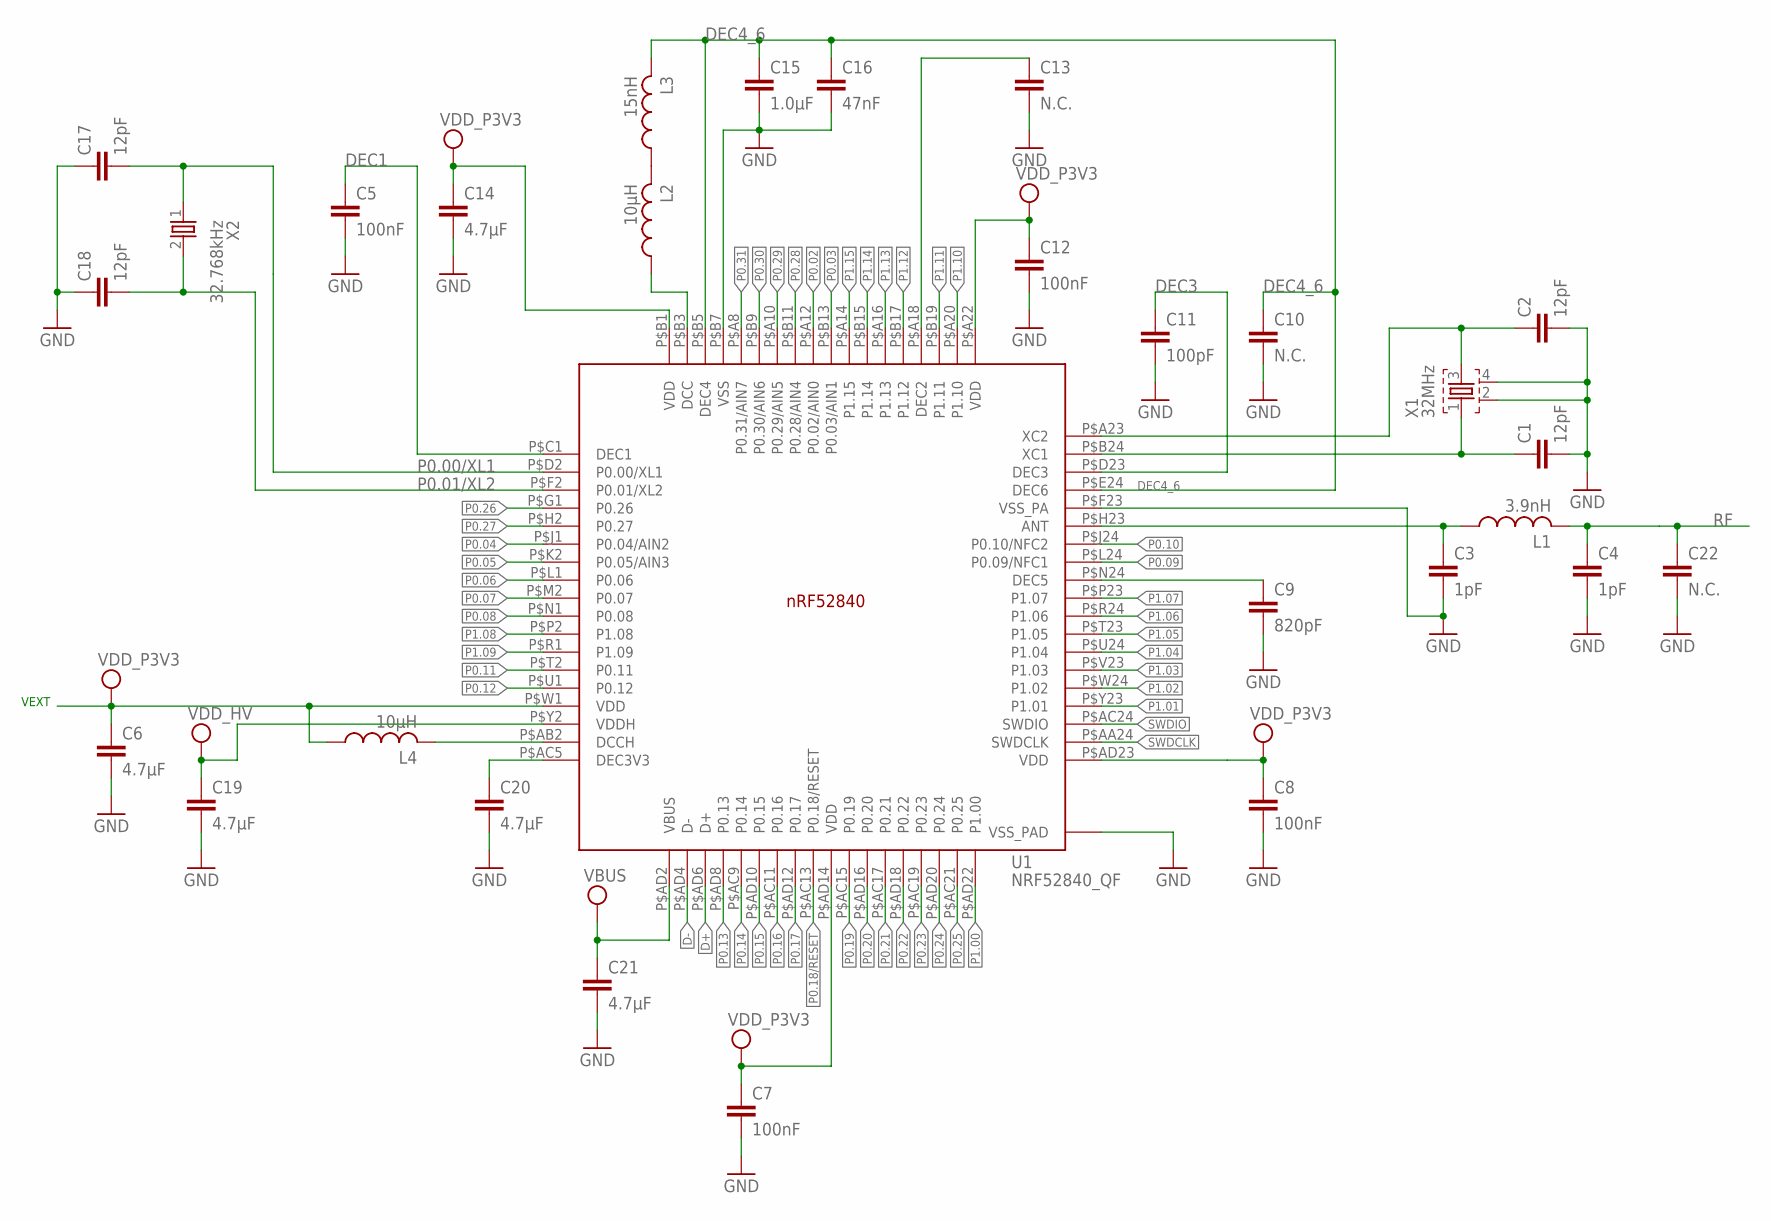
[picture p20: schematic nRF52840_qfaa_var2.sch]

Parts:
C1, C2, C17, C18: 12pF; RESC0402_N
C3, C4: 1pF; RESC0402_N
C5, C7, C8, C12: 100nF; RESC0402_N
C6, C14, C19, C20, C21: 4.7µF; RESC0603_N
C9: 820pF; RESC0402_N
C10, C13, C22: N.C.; RESC0402_N
C11: 100pF; RESC0402_N
C15: 1.0µF; RESC0603_N
C16: 47nF; RESC0402_N
L1: 3.9nH; RESC0402_N
L2, L4: 10µH; RESC0603_N
L3: 15nH; RESC0402_N
U1: NRF52840_QF; AQFN50P700X700X85_HS-74N
X1: 32MHz; BT-XTAL_2016_N
X2: 32.768kHz; XTAL_3215_N

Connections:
ANT: C3.1, L1.1, U1.P$H23 (ANT)
D+: U1.P$AD6 (D+)
D-: U1.P$AD4 (D-)
DCC: L2.1, U1.P$B3 (DCC)
DEC1: C5.1, U1.P$C1 (DEC1)
DEC2: C13.1, U1.P$A18 (DEC2)
DEC3: C11.1, U1.P$D23 (DEC3)
DEC3V3: C20.1, U1.P$AC5 (DEC3V3)
DEC4_6: C10.1, C15.1, C16.1, L3.2, U1.P$B5 (DEC4), U1.P$E24 (DEC6)
DEC5: C9.1, U1.P$N24 (DEC5)
GND: C1.2, C2.2, C3.2, C4.2, C5.2, C6.2, C7.2, C8.2, C9.2, C10.2, C11.2, C12.2, C13.2, C14.2, C15.2, C16.2, C17.1, C18.1, C19.2, C20.2, C21.2, C22.2, U1.P$74 (VSS_PAD), U1.P$75 (VSS_PAD), U1.P$76 (VSS_PAD), U1.P$77 (VSS_PAD), U1.P$78 (VSS_PAD), U1.P$79 (VSS_PAD), U1.P$80 (VSS_PAD), U1.P$81 (VSS_PAD), U1.P$82 (VSS_PAD), U1.P$83 (VSS_PAD), U1.P$84 (VSS_PAD), U1.P$85 (VSS_PAD), U1.P$86 (VSS_PAD), U1.P$87 (VSS_PAD), U1.P$88 (VSS_PAD), U1.P$89 (VSS_PAD), U1.P$90 (VSS_PAD), U1.P$B7 (VSS), U1.P$F23 (VSS_PA), X1.2, X1.4
unnamed: L4.2, U1.P$AB2 (DCCH)
unnamed: L2.2, L3.1
P0.00/XL1: C17.2, U1.P$D2 (P0.00/XL1), X2.1
P0.01/XL2: C18.2, U1.P$F2 (P0.01/XL2), X2.2
P0.02: U1.P$A12 (P0.02/AIN0)
P0.03: U1.P$B13 (P0.03/AIN1)
P0.04: U1.P$J1 (P0.04/AIN2)
P0.05: U1.P$K2 (P0.05/AIN3)
P0.06: U1.P$L1 (P0.06)
P0.07: U1.P$M2 (P0.07)
P0.08: U1.P$N1 (P0.08)
P0.09: U1.P$L24 (P0.09/NFC1)
P0.10: U1.P$J24 (P0.10/NFC2)
P0.11: U1.P$T2 (P0.11)
P0.12: U1.P$U1 (P0.12)
P0.13: U1.P$AD8 (P0.13)
P0.14: U1.P$AC9 (P0.14)
P0.15: U1.P$AD10 (P0.15)
P0.16: U1.P$AC11 (P0.16)
P0.17: U1.P$AD12 (P0.17)
P0.18/RESET: U1.P$AC13 (P0.18/RESET)
P0.19: U1.P$AC15 (P0.19)
P0.20: U1.P$AD16 (P0.20)
P0.21: U1.P$AC17 (P0.21)
P0.22: U1.P$AD18 (P0.22)
P0.23: U1.P$AC19 (P0.23)
P0.24: U1.P$AD20 (P0.24)
P0.25: U1.P$AC21 (P0.25)
P0.26: U1.P$G1 (P0.26)
P0.27: U1.P$H2 (P0.27)
P0.28: U1.P$B11 (P0.28/AIN4)
P0.29: U1.P$A10 (P0.29/AIN5)
P0.30: U1.P$B9 (P0.30/AIN6)
P0.31: U1.P$A8 (P0.31/AIN7)
P1.00: U1.P$AD22 (P1.00)
P1.01: U1.P$Y23 (P1.01)
P1.02: U1.P$W24 (P1.02)
P1.03: U1.P$V23 (P1.03)
P1.04: U1.P$U24 (P1.04)
P1.05: U1.P$T23 (P1.05)
P1.06: U1.P$R24 (P1.06)
P1.07: U1.P$P23 (P1.07)
P1.08: U1.P$P2 (P1.08)
P1.09: U1.P$R1 (P1.09)
P1.10: U1.P$A20 (P1.10)
P1.11: U1.P$B19 (P1.11)
P1.12: U1.P$B17 (P1.12)
P1.13: U1.P$A16 (P1.13)
P1.14: U1.P$B15 (P1.14)
P1.15: U1.P$A14 (P1.15)
RF: C4.1, C22.1, L1.2
SWDCLK: U1.P$AA24 (SWDCLK)
SWDIO: U1.P$AC24 (SWDIO)
VBUS: C21.1, U1.P$AD2 (VBUS)
VDD_HV: C19.1, U1.P$Y2 (VDDH)
VDD_P3V3: C6.1, C7.1, C8.1, C12.1, C14.1, L4.1, U1.P$A22 (VDD), U1.P$AD14 (VDD), U1.P$AD23 (VDD), U1.P$B1 (VDD), U1.P$W1 (VDD)
XC1: C1.1, U1.P$B24 (XC1), X1.1
XC2: C2.1, U1.P$A23 (XC2), X1.3

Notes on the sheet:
VEXT


Board: 4 copper layers, 22.5 x 19.5 mm, 29 parts (0 on the bottom side), 19 nets.

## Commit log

2017-07-22 Adding initial KiCAD version of nRF52832_qfaa_nfc project
    [nRF52832_qfaa_nfc.kicad_pcb, nRF52832_qfaa_nfc.sch]
2017-07-22 Adding *.kicad_pcb-bak to git ignore file
2017-07-23 Save work in progress. Working on NFC connector footprint
    [nRF52832_qfaa_nfc.kicad_pcb, nRF52832_qfaa_nfc.sch]
2017-07-23 Save work in progress before working on RF Antenna
    [nRF52832_qfaa_nfc.kicad_pcb]
2017-07-24 Update footprint of nRF52840 IC
    [nRF52832_qfaa_nfc.kicad_pcb]
2017-07-24 Fix libraries' path
    [nRF52832_qfaa_nfc.sch]
2017-07-24 Fix file permission
    [nRF52832_qfaa_nfc.sch]
2017-07-24 Resized Components' Value Label
    [nRF52832_qfaa_nfc.kicad_pcb]
2017-07-24 reset file permission
    [nRF52832_qfaa_nfc.kicad_pcb]
2017-07-24 Exporting Modic_misc to KiCad format
2017-07-26 Library Nordic_nRF exported to Kicad format
2017-07-26 Update KiCad library Nordic_nRF
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2017-07-27 Update KiCAD version of Nordic Libraries (still a WIP)
2017-07-27 Adding footprint 2450AT18B100.kicad_mod and Keystone_3000_1x12mm-CoinCell.kicad_mod
2017-07-28 Update Kicad Library (Adding footprint and 3D model for Screw and Spacer)
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2017-07-29 Reference Project nRF52832_qfaa_nfc ready
    [nRF52832_qfaa_nfc.kicad_pcb, nRF52832_qfaa_nfc.sch]
2017-07-29 Copy project nRF52832_qfaa_nfc as nRF52832_qfaa_dcdc
    [nRF52832_qfaa_dcdc.kicad_pcb, nRF52832_qfaa_dcdc.sch]
2017-07-29 Update Reference Project nRF52832_qfaa_dcdc before open it with KiCad
    [nRF52832_qfaa_dcdc.sch]
2017-07-29 Reference Project nRF52832_qfaa_dcdc ready
    [nRF52832_qfaa_dcdc.kicad_pcb, nRF52832_qfaa_dcdc.sch]
2017-07-29 Copying Reference Project nRF52832_qfaa_dcdc as nRF52832_qfaa
    [nRF52832_qfaa.kicad_pcb, nRF52832_qfaa.sch]
2017-07-29 Update Reference Project nRF52832_qfaa before open it with KiCad
    [nRF52832_qfaa.sch]
2017-07-29 Reference Project nRF52832_qfaa ready
    [nRF52832_qfaa.kicad_pcb, nRF52832_qfaa.sch]
2017-07-29 Addinig initial version of Project nRF52832_MCU_Board
    [nRF528323_MCU.sch, nRF52832_MCU_Board.kicad_pcb, nRF52832_MCU_Board.sch]
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2017-07-30 Update WIP
    [nRF528323_MCU.sch, nRF52832_MCU_Board.kicad_pcb, nRF52832_MCU_Board.sch]
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2017-07-30 Adding Schematic file
    [PowerSupply.sch]
2017-07-30 Update KiCad Library (Symbols, Footprint adn 3D Models)
2017-07-30 Update KiCad Projec nRF52832_MCU_Board
    [Peripherics.sch, PowerSupply.sch, nRF528323_MCU.sch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]
2017-07-30 Update 3D models Screw and Spacer 3mm
2017-07-30 Update library Nordic_misc (Mounting Hole)
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2017-07-30 Update KiCad project nRF52832_MCU_Board
    [Peripherics.sch, nRF52832_MCU_Board.kicad_pcb]
2017-07-31 Update KiCAD Libraries Nordic_mis.pretty and Nordic_nRF.pretty
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2017-08-01 Update KiCAD Project nRF52832_MCU_Board
    [Peripherics.sch, PowerSupply.sch, nRF528323_MCU.sch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]
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2017-08-03 Update kicad-_pcb file of project nRF52832_MCU_Board
    [nRF52832_MCU_Board.kicad_pcb]
2017-08-03 Adding nRF52840_reference for KiCAD (initial design)
    [nRF52840_qfaa_nfc.kicad_pcb, nRF52840_qfaa_nfc.sch]
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2017-08-04 Update KiCAD Project nRF52840_qfaa_nfc
    [nRF52840_qfaa_nfc.kicad_pcb, nRF52840_qfaa_nfc.sch]
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2017-08-04 Copy KiCAD Project nRF52840_qfaa_nfc as nRF52840_qfaa_dcdc
    [nRF52840_qfaa_dcdc.kicad_pcb, nRF52840_qfaa_dcdc.sch]
2017-08-04 Update KiCAD project nRF52840_qfaa_dcdc
    [nRF52840_qfaa_dcdc.sch]
2017-08-04 Copy KiCAD Project nRF52840_qfaa_dcdc as nRF52840_qfaa
    [nRF52840_qfaa_dcdc.kicad_pcb, nRF52840_qfaa_dcdc.sch]
2017-08-04 Update KiCAD Project nRF52840_qfaa.net
    [nRF52840_qfaa_dcdc.sch]
2017-08-04 Renamed files
    [nRF52840_qfaa.kicad_pcb, nRF52840_qfaa.sch]
2017-08-04 Update KiCAD Project nRF52840_qfaa
    [nRF52840_qfaa.kicad_pcb, nRF52840_qfaa.sch]
2017-08-04 Copy nRF52840_qfaa_nfc as nRF52840_MCU_Board
    [nRF52840_qfaa_nfc.kicad_pcb, nRF52840_qfaa_nfc.sch]
2017-08-04 Update KiCAD Project nRF52840_MCU_Board
    [nRF52840_MCU_Board.sch]
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2017-08-10 Reload footprint
    [nRF52840_MCU_Board.kicad_pcb]
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2017-08-31 Update nRF52832_reference
    [nRF52832_qfaa.kicad_pcb, nRF52832_qfaa.sch, nRF52832_qfaa_dcdc.kicad_pcb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]
2017-08-31 Update nRF52840_reference
    [nRF52840_qfaa.kicad_pcb, nRF52840_qfaa_dcdc.kicad_pcb, nRF52840_qfaa_nfc.kicad_pcb]
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2017-08-31 Update project nRF52832_MCU_Board
    [nRF52832_MCU_Board.kicad_pcb]
2017-08-31 Update project nRF52840_MCU_Board
    [nRF52840_MCU_Board.kicad_pcb]
2017-08-31 Update minors trace changes
    [nRF52832_MCU_Board.kicad_pcb]
2017-09-05 Update nRF52832_MCU_Board
    [Peripherics.sch, PowerSupply.sch, nRF528323_MCU.sch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]
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2019-06-21 Small label/designator update, fixes #6
    [nRF52832_qfaa_dcdc.brd, nRF52832_qfaa_dcdc.sch]
2019-06-21 Same fixes as in qfaa_dcdc
    [nRF52832_qfaa.brd, nRF52832_qfaa.sch, nRF52832_qfaa_nfc.brd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]
2019-06-21 Removed 'nRF52832_MCU-board'
    [nRF52832_MCU.brd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]
2019-06-21 Resized nRF52810 schematic symbol to same size as nRF52832, also renamed to the proper Packet variant name
2019-06-21 Added nRF52810_qfaa reference layout (copied from nRF52832_qfaa, pin compatible)
    [nRF52810_qfaa.brd, nRF52810_qfaa.sch, nRF52810_qfaa_dcdc.brd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]
2019-06-21 Eagle did not save properly
    [nRF52810_qfaa_dcdc.brd, nRF52810_qfaa_dcdc.sch]
2019-06-21 Added nRF52810_qcaa reference
    [nRF52810_qcaa.brd, nRF52810_qcaa.sch, nRF52810_qcaa_dcdc.brd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]
2019-06-21 Started nRF52840 reference layout
    [nRF52840_qfaa_var1.brd, nRF52840_qfaa_var1.sch, nRF52840_qfaa_var2.brd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]
